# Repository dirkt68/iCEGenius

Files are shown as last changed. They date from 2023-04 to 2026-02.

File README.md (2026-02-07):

# iCEGenius (WIP)

**STILL A WORK IN PROGRESS, DONT USE UNTIL THIS MESSAGE IS GONE**

A low cost, low power, minimally sized FPGA development board based on the iCE40LP384 FPGA.

## Table of Contents
- [iCEGenius (WIP)](#icegenius-wip-1)
  - [Table of Contents](#table-of-contents-1)
  - [Project Goal](#project-goal-1)
  - [Setup](#setup-1)
  - [Directory Structure](#directory-structure-1)
  - [Support](#support-1)
  - [Wishlist](#wishlist-1)
  - [Author Information](#author-information-1)

## Project Goal

Hobbyist grade FPGAs are in relatively short supply and are typically complicated for new users to dive into. Even the cheapest ones still range in the 30-40 dollar territory, which can be prohibitively expensive for institutions or groups without a large budget. To fill this void, the iCEGenius has been developed as an educational tool for use in learning introductory to intermediate Verilog on a real hardware target.

{INSERT 3D RENDER PIC}

The iCEGenius has been designed with cost and ease of use in mind. The total bill of materials is only $13.00 USD, which is cheaper than any of the common development FPGAs on the market. The board is designed to fit comfortably into a standard breadboard with space for multiple connections on either pin. With 16 accessible GPIOs, the board is very expandable for anything from simple blinky LEDs to more complex designs.

{INSERT PIC OF BOARD ON BREADBOARD}

The toolchain is a Visual Studio Code extension which supports one click simulations using iverilog and gtkwave and full synthesis using yosys and nextpnr. The [oss-cad-suite](https://github.com/YosysHQ/oss-cad-suite-build) was used as the main backend as all the necessary programs were included by default. A custom program designed to flash the bitstream using the MCP2210 USB-SPI interface is used as the uploader. All of the complicated command line work is handled by the extension, allowing for a low barrier to entry to those who want to learn.

The PCB was developed in Kicad 7.0 and the extension supports Visual Studio Code 1.77.0 and greater.

**IMPORTANT: ONLY WINDOWS IS SUPPORTED AT THIS TIME**

## Setup

1. Grab the latest binary of oss-cad-suite from https://github.com/YosysHQ/oss-cad-suite-build and extract to `C:/oss-cad-suite`.
2. Install the latest binary of the iCEGenius Programmer from the [`Releases`](https://github.com/dirkt68/iCEGenius/releases/) Tab.
3. Install [Visual Studio Code](https://code.visualstudio.com) and install the iCEGenius (ADD HYPERLINK TO EXTENSION) extension.
4. Write some Verilog and upload to your board!

## Directory Structure

- board (where anything related to PCB lives)
  - bom (bill of materials for v2 and v1)
  - iCEGenius-backups (kicad automatic backups)
  - information (datasheets and a pinout guide for the FPGA)
  - jlcpcb (where the production files are autogenerated (gerbers, cpl, etc.))
  - pdf (easy reference to schematic and layout)
  - sims (electronic simulations)
  - kicad board files (open in kicad)
- extension (where the vscode extension lives)
  - standard Visual Studio Code layout for an extension
- programmer (where the program to program the board lives)
  - etc (user guides, etc.)
  - includes (*.h files)
  - libs (*.lib files)
  - src (main code)

## Support
- Any suggestions are welcome! I will not be super active all the time, but I'd like to maintain the project as much as I can.

## Wishlist
- add linux and mac support
- host a prebuilt board somewhere where people can buy (where?)

## Author Information
- Made by Dirk Thieme for use in ECE 2372 for the Capstone Project Lab at Texas Tech University. Advised by Derek A. Johnston.

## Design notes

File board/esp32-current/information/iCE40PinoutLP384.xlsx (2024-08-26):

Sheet: Pinout
iCE40 Pinout LP384
Ball Function | Pin Type | Bank | (SG32) 32-Pin QFN Ball Number
IOL_1A | DPIO | 3 | -
IOL_1B | DPIO | 3 | -
IOL_2A | DPIO | 3 | 2 |  |  | 1 | 2 | 3 | 4 | 5 | 6 | 7 | 8
IOL_2B | DPIO | 3 | 1 |  |  | IO_2A | IO_2B | GND | VCCIO_3 | IOL_4A | IOL_4B_GBIN7 | IOL_5B | IOL_5A_GBIN6
IOL_3A | DPIO | 3 | - | 32 | IOT_52 |  |  |  |  |  |  |  |  | VCCIO_2 | 9
IOL_3B | DPIO | 3 | - | 31 | IOT_53 |  |  |  |  |  |  |  |  | CRESET_B | 10
IOL_4A | DPIO | 3 | 5 | 30 | IOT_50_GBIN1 |  |  |  |  |  |  |  |  | CDONE | 11
IOL_4B_GBIN7 | GBIN | 3 | 6 | 29/CLK_IN | IOT_49_GBIN0 |  |  |  | FPGA Pin Numbering |  |  |  |  | IOB_24_SDO | 12
IOL_5A_GBIN6 | GBIN | 3 | 8 | 28 | VCCIO_0 |  |  |  |  |  |  |  |  | IOB_25_SDI | 13
IOL_5B | DPIO | 3 | 7 | 27 | IOT_47 |  |  |  |  | I/O Pins (use) |  |  |  | IOB_26_SCK | 14
IOL_6A | DPIO | 3 | - | 26 | IOT_45 |  |  |  |  | Reserved (no use) |  |  |  | IOB_27_SS | 15
IOL_6B | DPIO | 3 | - | 25 | VCC |  |  |  |  |  |  |  |  | VCC_SPI | 16
IOL_7A | DPIO | 3 | - |  |  | VPP_2V5 | IOR_39 | IOR_38 | GND | IOR_36_GBIN2 | IOR_35_GBIN3 | IOR_34 | VCCIO_1
IOL_7B | DPIO | 3 | - |  |  | 24 | 23 | 22 | 21 | 20 | 19 | 18 | 17
IOL_8A | DPIO | 3 | -
IOL_8B | DPIO | 3 | -
IOB_16 | PIO | 2 | -
IOB_17 | PIO | 2 | -
IOB_18 | PIO | 2 | -
IOB_19 | PIO | 2 | -
IOB_20 | PIO | 2 | -
IOB_21_GBIN5 | GBIN | 2 | -
IOB_22_GBIN4_CBSEL0 | GBIN | 2 | -
IOB_23_CBSEL1 | PIO | 2 | -
CDONE | CONFIG | 2 | 11
CRESET_B | CONFIG | 2 | 10
IOB_24_SDO | SPI | SPI | 12
IOB_25_SDI | SPI | SPI | 13
IOB_26_SCK | SPI | SPI | 15
IOB_27_SS | SPI | SPI | 14
VCC_SPI | SPI | SPI | 16
IOR_28 | PIO | 1 | -
IOR_29 | PIO | 1 | -
IOR_30 | PIO | 1 | -
IOR_31 | PIO | 1 | -
IOR_33 | PIO | 1 | -
IOR_34 | PIO | 1 | 18
IOR_35_GBIN3 | GBIN | 1 | 19
IOR_36_GBIN2 | GBIN | 1 | 20
IOR_37 | PIO | 1 | -
IOR_38 | PIO | 1 | 22
IOR_39 | PIO | 1 | 23
IOR_40 | PIO | 1 | -
IOR_41 | PIO | 1 | -
IOR_42 | PIO | 1 | -
IOR_43 | PIO | 1 | -
VPP_2V5 | VPP | VPP | 24
VPP_FAST | VPP | VPP | -
IOT_44 | PIO | 0 | -
IOT_45 | PIO | 0 | 26
IOT_46 | PIO | 0 | -
IOT_47 | PIO | 0 | 27
IOT_48 | PIO | 0 | -
IOT_49_GBIN0 | GBIN | 0 | 29
IOT_50_GBIN1 | GBIN | 0 | 30
IOT_51 | PIO | 0 | -
IOT_52 | PIO | 0 | 32
IOT_53 | PIO | 0 | 31
IOT_54 | PIO | 0 | -
IOT_55 | PIO | 0 | -
GND | GND | GND | 3
GND | GND | GND | 21
GND | GND | GND | -
GND | GND | GND | -
VCC | VCC | VCC | 25
VCC | VCC | VCC | -
VCC | VCC | VCC | -
VCCIO_0 | VCCIO | VCCIO | 28
VCCIO_1 | VCCIO | VCCIO | 17
VCCIO_2 | VCCIO | VCCIO | 9
VCCIO_3 | VCCIO | VCCIO | 4
VCCIO_2_3 | VCCIO | VCCIO | -

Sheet: Revision History
Version | Date | Description
1.1 | 2013-06-27 | Removal of CM81 package. Included package ordering code.
1.0 | 2013-03-13 | Initial Release

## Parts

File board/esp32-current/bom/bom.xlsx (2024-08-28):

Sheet: v2
Mouser Part Number | Part Name | Price | Amount/Unit | Sub-Total | Notes | Total/Amt | Desired Amt
842-ICE40LP384SG32 | ICE40LP384-SG32 | $2.28 | 1 | $2.28 | FPGA | $13.44 | 1
454-W25Q80DVSNIG | W25Q80DVSNIG | $0.49 | 1 | $0.49 | SPI Flash - 8Mb
579-MCP1727-3302E/MF | MCP1727-3302E/MF | $1.11 | 1 | $1.11 | 3V3 Regulator | Total/Unit
998-MIC5365-1.2YC5TR | MIC5365-1.2YC5-TR | $0.19 | 1 | $0.19 | 1V2 Regulator | $13.44
833-1N4148W-TP | 1N4148W-TP | $0.11 | 1 | $0.11 | Diode to Drop 3V3 to ~2.5V
520-TXO32CSMV400BNTR | ECS-TXO-32CSMV-400-BN-TR | $1.93 | 1 | $1.93 | 40MHz TCXO | Savings from v1
998-PL133-27GC-R | PL133-27GC-R | $0.97 | 1 | $0.97 | Clock 1:2 Buffer | 5.485232068%
356-ESP32-C6FH4 | ESP32-C6FH4 | $2.06 | 1 | $2.06 | USB-SPI Bridge
187-CL05A105KO5NNND | CL05A105KO5NNND | $0.04 | 13 | $0.52 | 1u X5R 0402 10% Cap
81-GRM155R61A106ME1J | GRM155R61A106ME11J | $0.11 | 2 | $0.22 | 10u X5R 0402 20% Cap
581-0201ZD104KAT4A | 0201ZD104KAT4A | $0.02 | 14 | $0.28 | 100n X5R 0201 10% Cap
791-RGC1/16SC5101DTH | RGC1/16SC5101DTH | $0.10 | 2 | $0.20 | 5.1k 0402 0.5% Res
756-ASC0402-10KFT10 | ASC0402-10KFT10 | $0.08 | 6 | $0.48 | 10k 0402 1% Res
81-LQG15HZ2N0B02D | LQG15HZ2N0B02D | $0.17 | 1 | $0.17 | 2n 0.9A Inductor
640-USB4105-GF-A-060 | USB4105-GF-A-060 | $0.81 | 1 | $0.81 | USB C Connector
710-150060RS75000 | 150060RS75000 | $0.15 | 1 | $0.15 | Red LED 0603
963-MAASL063SB7103KF | MAASL063SB7103KFCA01 | $0.12 | 1 | $0.12 | 0.01n X7R 10% 0201 10% Cap
595-ESD321DYAR | ESD321DYAR | $0.45 | 3 | $1.35 | ESD Diodes

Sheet: v1
Mouser Part Number | Part Name | Price | Amount/Unit | Sub-Total | Notes | Total/Unit
842-ICE40LP384SG32 | ICE40LP384-SG32 | $2.17 | 1 | $2.17 | FPGA | $14.22
454-W25Q80DVSNIG | W25Q80DVSNIG | $0.52 | 1 | $0.52 | SPI Flash - 8Mb
621-PI5C3257ZHDEX | PI5C3257ZHDEX | $0.60 | 1 | $0.60 | SPI MUX
595-TLV74033PDBVR | TLV74033PDBVR | $0.25 | 1 | $0.25 | 3V3 Regulator
998-MIC5365-1.2YC5TR | MIC5365-1.2YC5-TR | $0.19 | 1 | $0.19 | 1V2 Regulator
833-1N4148W-TP | 1N4148W-TP | $0.10 | 1 | $0.10 | Diode to Drop 3V3 to ~2.5V
815-ABM8AIG-12MHZ1ZT | ABM8AIG-12.000MHZ-1Z-T | $0.72 | 1 | $0.72 | 12MHz Clock
895-FT4222HQ-D-T | FT4222HQ-D-T | $3.62 | 1 | $3.62 | USB-SPI IC
187-CL05A105KO5NNND | CL05A105KO5NNND | $0.04 | 14 | $0.56 | 1u X5R 0402 10% Cap
81-GRM0335C1E240GA1D | GRM0335C1E240GA01D | $0.10 | 2 | $0.20 | 24p C0G 0201 2% Cap
603-CC402KRX5R6BB474 | CC0402KRX5R6BB474 | $0.10 | 1 | $0.10 | 470n X7R 0402 10% Cap
581-0201ZD104KAT4A | 0201ZD104KAT4A | $0.02 | 12 | $0.24 | 0.1u X5R 0201 10% Cap
791-RGC1/16SC5101DTH | RGC1/16SC5101DTH | $0.10 | 2 | $0.20 | 5.1k 0402 0.5% Res
603-RC0402FR-1312KL | RC0402FR-1312KL | $0.01 | 7 | $0.07 | 12k 0402 1% Res
756-ASC0402-10KFT10 | ASC0402-10KFT10 | $0.08 | 5 | $0.40 | 10k 0402 1% Res
71-CRCW04021M00FKEE | CRCW04021M00FKEE | $0.10 | 1 | $0.10 | 1M 0402 1% Res
640-USB4105-GF-A-060 | USB4105-GF-A-060 | $0.81 | 1 | $0.81 | USB C Connector
710-150060RS75000 | 150060RS75000 | $0.15 | 1 | $0.15 | Red LED 0603
576-SC1006-01LTG | SC1006-01LTG | $0.45 | 3 | $1.35 | ESD Diodes
Slide Switch |  | $1.87 | 1 | $1.87 | Don’t remember exact

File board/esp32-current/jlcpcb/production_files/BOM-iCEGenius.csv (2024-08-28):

Comment | Designator | Footprint | LCSC
1u | C1 | C_0402_1005Metric
100n | C10 | C_0201_0603Metric
100n | C11 | C_0201_0603Metric
100n | C12 | C_0201_0603Metric
1u | C13 | C_0402_1005Metric
100n | C14 | C_0201_0603Metric
100n | C15 | C_0201_0603Metric
100n | C16 | C_0201_0603Metric
1u | C17 | C_0402_1005Metric
100n | C18 | C_0201_0603Metric
1u | C19 | C_0402_1005Metric
10u | C2 | C_0402_1005Metric
100n | C20 | C_0201_0603Metric
1u | C21 | C_0402_1005Metric
100n | C22 | C_0201_0603Metric
1u | C23 | C_0402_1005Metric
100n | C24 | C_0201_0603Metric
1u | C25 | C_0402_1005Metric
100n | C26 | C_0201_0603Metric
1u | C27 | C_0402_1005Metric
100n | C28 | C_0201_0603Metric
1u | C29 | C_0402_1005Metric
1u | C3 | C_0402_1005Metric
100n | C30 | C_0201_0603Metric
1u | C4 | C_0402_1005Metric
1u | C5 | C_0402_1005Metric
10n | C6 | C_0201_0603Metric
10u | C7 | C_0402_1005Metric
1u | C8 | C_0402_1005Metric
100n | C9 | C_0201_0603Metric
1N4148W-TP | D1 | D_SOD-123
ESD321 | D2 | D_0402_1005Metric_TVS
ESD321 | D3 | D_0402_1005Metric_TVS
ESD321 | D4 | D_0402_1005Metric_TVS
FPGA_DONE_G | D5 | LED_0603_1608Metric
USB4105-GF-A-060 | J1 | USB_C_Receptacle_GCT_USB4105-xx-A_16P_TopMnt_Horizontal
LEFT | J2 | PinSocket_1x10_P2.54mm_Vertical
RIGHT | J3 | PinSocket_1x10_P2.54mm_Vertical
LQG15HZ2N0B02D | L1 | L_0402_1005Metric
5k1 | R1 | R_0402_1005Metric
5k1 | R2 | R_0402_1005Metric
10k | R3 | R_0402_1005Metric
10k | R4 | R_0402_1005Metric
10k | R5 | R_0402_1005Metric
10k | R6 | R_0402_1005Metric
10k | R7 | R_0402_1005Metric
10k | R8 | R_0402_1005Metric
MCP1727-3302xMF | U1 | DFN-8-1EP_3x3mm_P0.65mm_EP1.55x2.4mm
MIC5365-1.2YC5 | U2 | SOT-353_SC-70-5
ESP32-C6FH4 | U3 | QFN50P500X500X90-33N
W25Q80DVSNIG | U4 | SOIC127P600X175-8N
ICE40LP384-SG32 | U5 | HVQFN-32-1EP_5x5mm_P0.5mm_EP3.1x3.1mm
PL133-27GC-R | U6 | SON40P200X130X60-7N-D
ECS-TXO-32CSMV-400-BN-TR | Y1 | ECSTXO32CSMV400BNTR

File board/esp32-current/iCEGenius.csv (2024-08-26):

Source: | D:\Documents\School\TTU\summer23\project-lab-4\iCEGenius\board\iCEGenius.kicad_sch
Date: | Tue Jun 27 13:58:00 2023
Tool: | Eeschema 7.0.2
Generator: | C:\Program Files\KiCad\7.0\bin\scripting\plugins/bom_csv_grouped_by_value.py
Component Count: | 52
Collated Components:
Item | Qty | Reference(s) | Value | LibPart | Footprint | Datasheet | DNP | Height | MANUFACTURER | Manufacturer_Name | Manufacturer_Part_Number | Mouser Part Number | Mouser Price/Stock | Sim.Device | Sim.Pins
1 | 12 | C1, C2, C3, C4, C5, C12, C14, C16, C18, C20, C22, C24 | 1u | Device:C_Small | Capacitor_SMD:C_0402_1005Metric | ~
2 | 10 | C6, C9, C10, C13, C15, C17, C19, C21, C23, C25 | 100n | Device:C_Small | Capacitor_SMD:C_0201_0603Metric | ~
3 | 2 | C7, C8 | 24p | Device:C_Small | Capacitor_SMD:C_0201_0603Metric | ~
4 | 1 | C11 | 10n | Device:C_Small | Capacitor_SMD:C_0201_0603Metric | ~
5 | 1 | D1 | 1N4148W-TP | Device:D_Small_Filled | Diode_SMD:D_SOD-123 | ~ |  |  |  |  |  |  |  | D | 1=K 2=A
6 | 3 | D2, D3, D4 | SC1006-01LTG | Device:D_TVS_Filled | PCM_Diode_SMD_AKL:D_SOD-523_TVS | ~
7 | 1 | D5 | CDONE | Device:LED_Small | PCM_Diode_SMD_AKL:D_0603_1608Metric | ~
8 | 1 | IC1 | MCP2210-I_MQ | SamacSys_Parts:MCP2210-I_MQ | SamacSys_Parts:QFN65P500X500X100-21N-D |  |  | 1 |  | Microchip | MCP2210-I/MQ | 579-MCP2210IMQ | https://www.mouser.co.uk/ProductDetail/Microchip-Technology/MCP2210-I-MQ?qs=hort8UWU32pLWgskQOyvyg%3D%3D
9 | 1 | J1 | USB4105-GF-A-060 | Connector:USB_C_Receptacle_USB2.0 | Connector_USB:USB_C_Receptacle_GCT_USB4105-xx-A_16P_TopMnt_Horizontal | https://www.usb.org/sites/default/files/documents/usb_type-c.zip
10 | 1 | J2 | LEFT | Connector:Conn_01x10_Pin | Connector_PinSocket_2.54mm:PinSocket_1x10_P2.54mm_Vertical | ~
11 | 1 | J3 | RIGHT | Connector:Conn_01x10_Pin | Connector_PinSocket_2.54mm:PinSocket_1x10_P2.54mm_Vertical | ~
12 | 1 | Q1 | MMBT3904-TP | PCM_Transistor_BJT_AKL:MMBT3904 | PCM_Package_TO_SOT_SMD_AKL:SOT-23 | https://www.tme.eu/Document/12bff749841e3a356e683e9a8e7e4119/2N3904BU-DTE.pdf
13 | 2 | R1, R2 | 5k1 | Device:R_Small | Resistor_SMD:R_0402_1005Metric | ~
14 | 1 | R3 | 1M | Device:R_Small | Resistor_SMD:R_0402_1005Metric | ~
15 | 8 | R4, R5, R6, R7, R8, R9, R10, R11 | 10k | Device:R_Small | Resistor_SMD:R_0402_1005Metric | ~
16 | 1 | U1 | BU33SD5WG-TR | SamacSys_Parts:BU33SD5WG-TR | SOT95P280X125-5N | https://componentsearchengine.com/Datasheets/1/BU33SD5WG-TR.pdf |  | 1.25 |  | ROHM Semiconductor | BU33SD5WG-TR | 755-BU33SD5WG-TR | https://www.mouser.co.uk/ProductDetail/ROHM-Semiconductor/BU33SD5WG-TR?qs=%2FKR40Cd6GUrQDzRkUEt69Q%3D%3D
17 | 1 | U2 | MIC5365-1.2YC5 | Regulator_Linear:MIC5365-3.3YC5 | Package_TO_SOT_SMD:SOT-353_SC-70-5 | http://ww1.microchip.com/downloads/en/DeviceDoc/mic5365.pdf
18 | 1 | U3 | W25Q80DVSNIG | SamacSys_Parts:W25Q80DVSNIG | SamacSys_Parts:SOIC127P600X175-8N | https://www.winbond.com/hq/search-resource-file.jsp?partNo=W25Q80DVSNIG&type=datasheet |  | 1.75 |  | Winbond | W25Q80DVSNIG | 454-W25Q80DVSNIG | https://www.mouser.co.uk/ProductDetail/Winbond/W25Q80DVSNIG?qs=qSfuJ%252Bfl%2Fd4U6qBd6DZUig%3D%3D
19 | 1 | U4 | ICE40LP384-SG32 | ICE40LP384-SG32:ICE40LP384-SG32 | Package_DFN_QFN:HVQFN-32-1EP_5x5mm_P0.5mm_EP3.1x3.1mm |  |  |  | Lattice Semiconductor
20 | 1 | Y1 | 815-ABM8AIG-12MHZ1ZT | Device:Crystal_GND24 | SamacSys_Parts:ABM8AIG25000MHZ122ZT3 | ~
21 | 1 | Y2 | ASFL1-100.000MHZ-L-T | SamacSys_Parts:ASFL1-100.000MHZ-L-T | SamacSys_Parts:ASFL1 | https://abracon.com/Oscillators/ASFL1.pdf |  | 1.3 |  | ABRACON | ASFL1-100.000MHZ-L-T

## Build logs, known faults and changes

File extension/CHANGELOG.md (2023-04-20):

# Change Log

All notable changes to the "iCEGenius-extension" extension will be documented in this file.

Check [Keep a Changelog](http://keepachangelog.com/) for recommendations on how to structure this file.

## [Unreleased]

- Initial release

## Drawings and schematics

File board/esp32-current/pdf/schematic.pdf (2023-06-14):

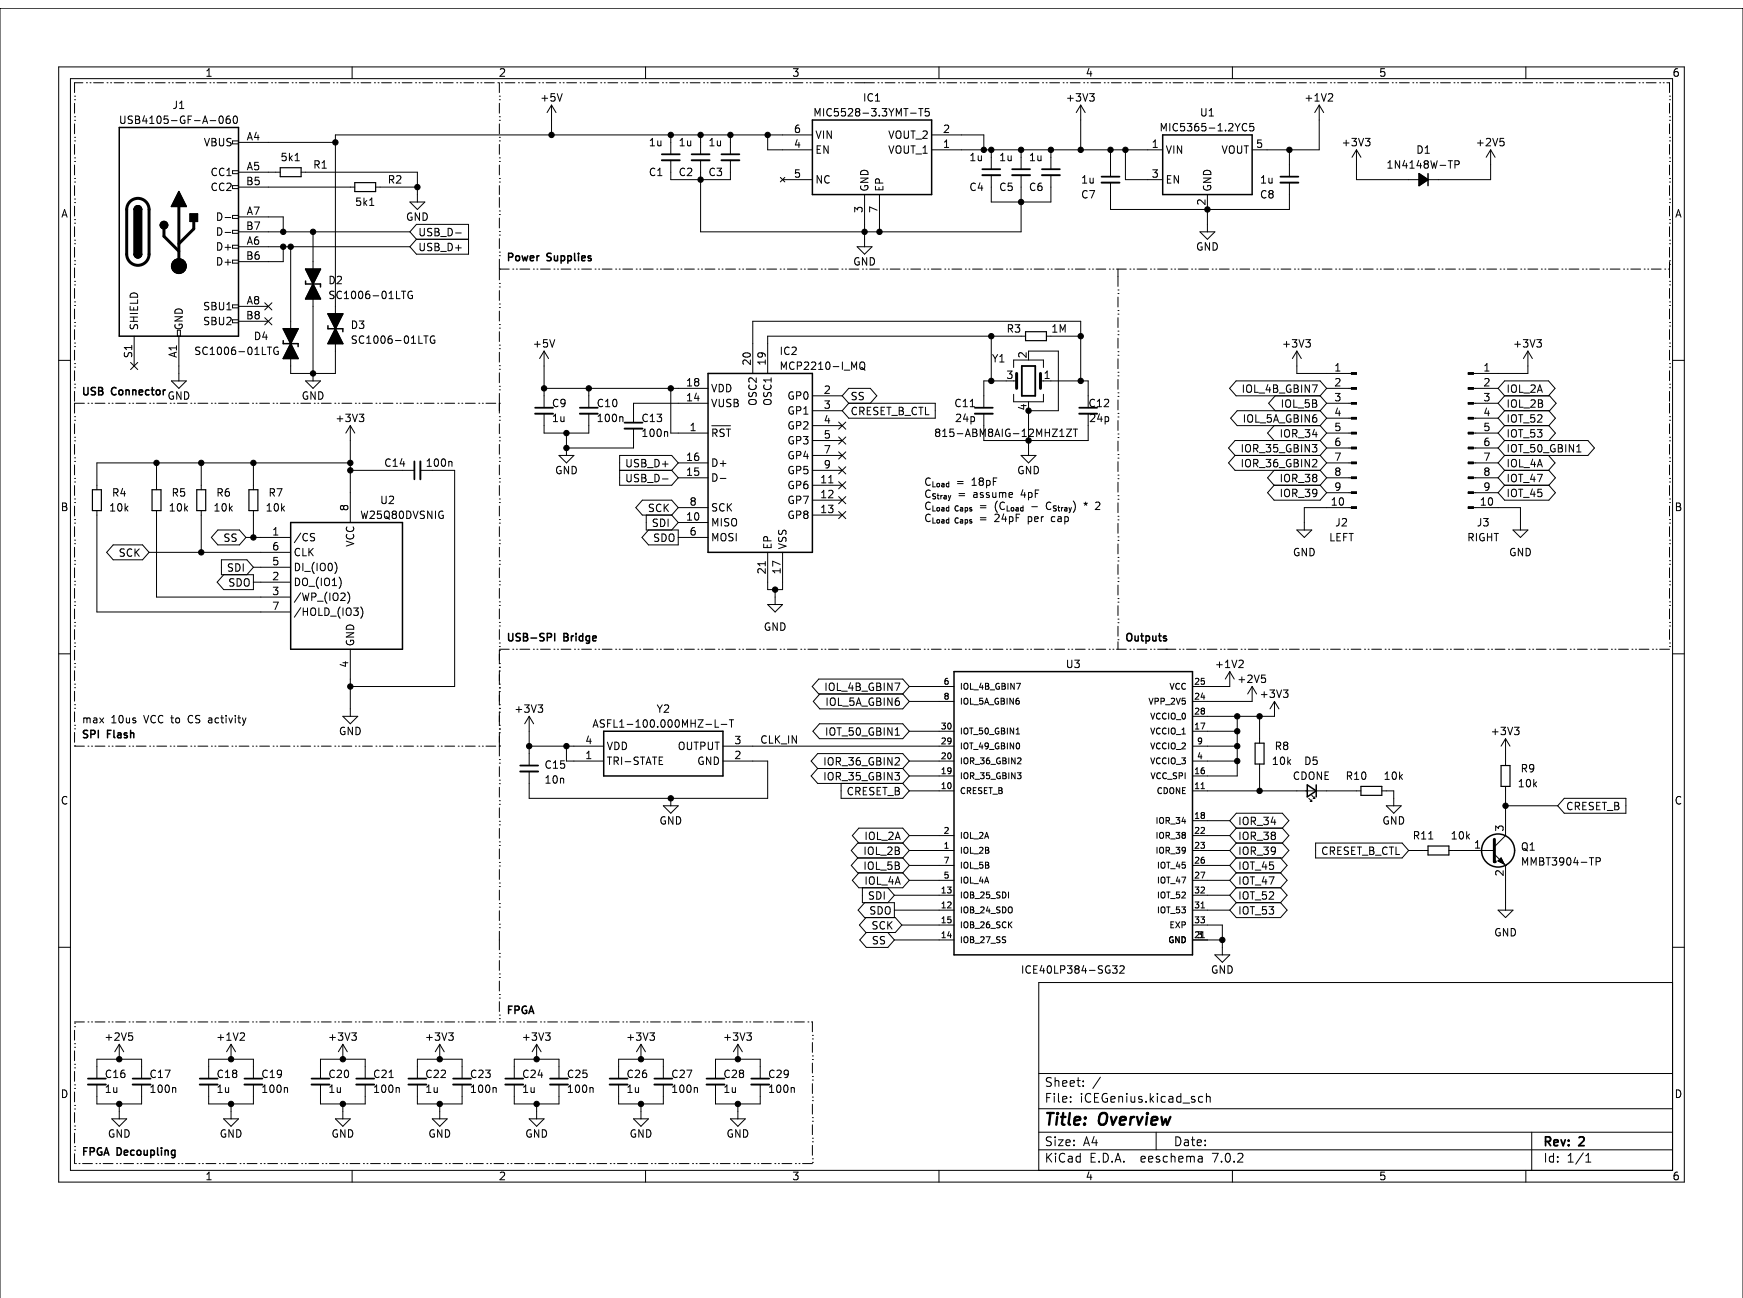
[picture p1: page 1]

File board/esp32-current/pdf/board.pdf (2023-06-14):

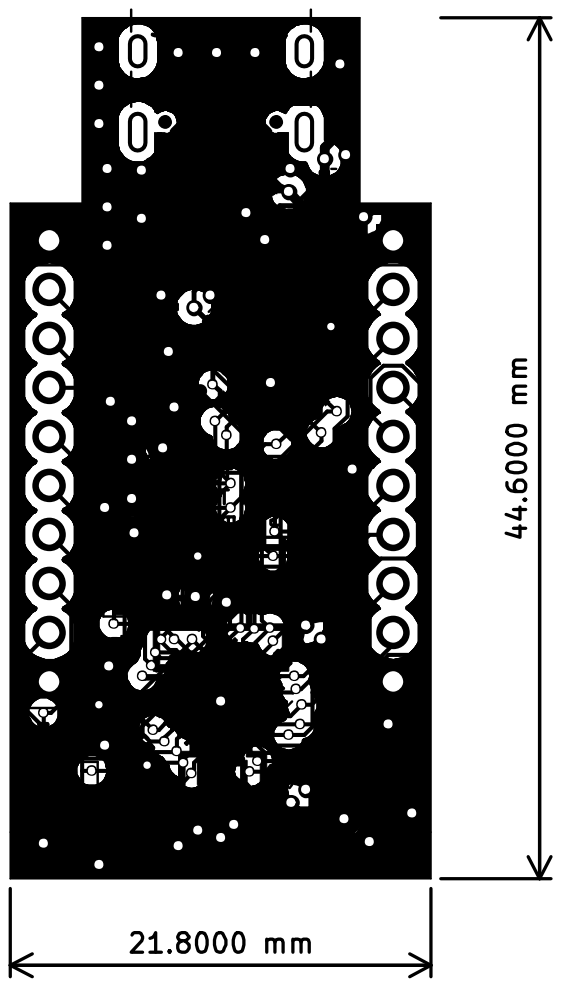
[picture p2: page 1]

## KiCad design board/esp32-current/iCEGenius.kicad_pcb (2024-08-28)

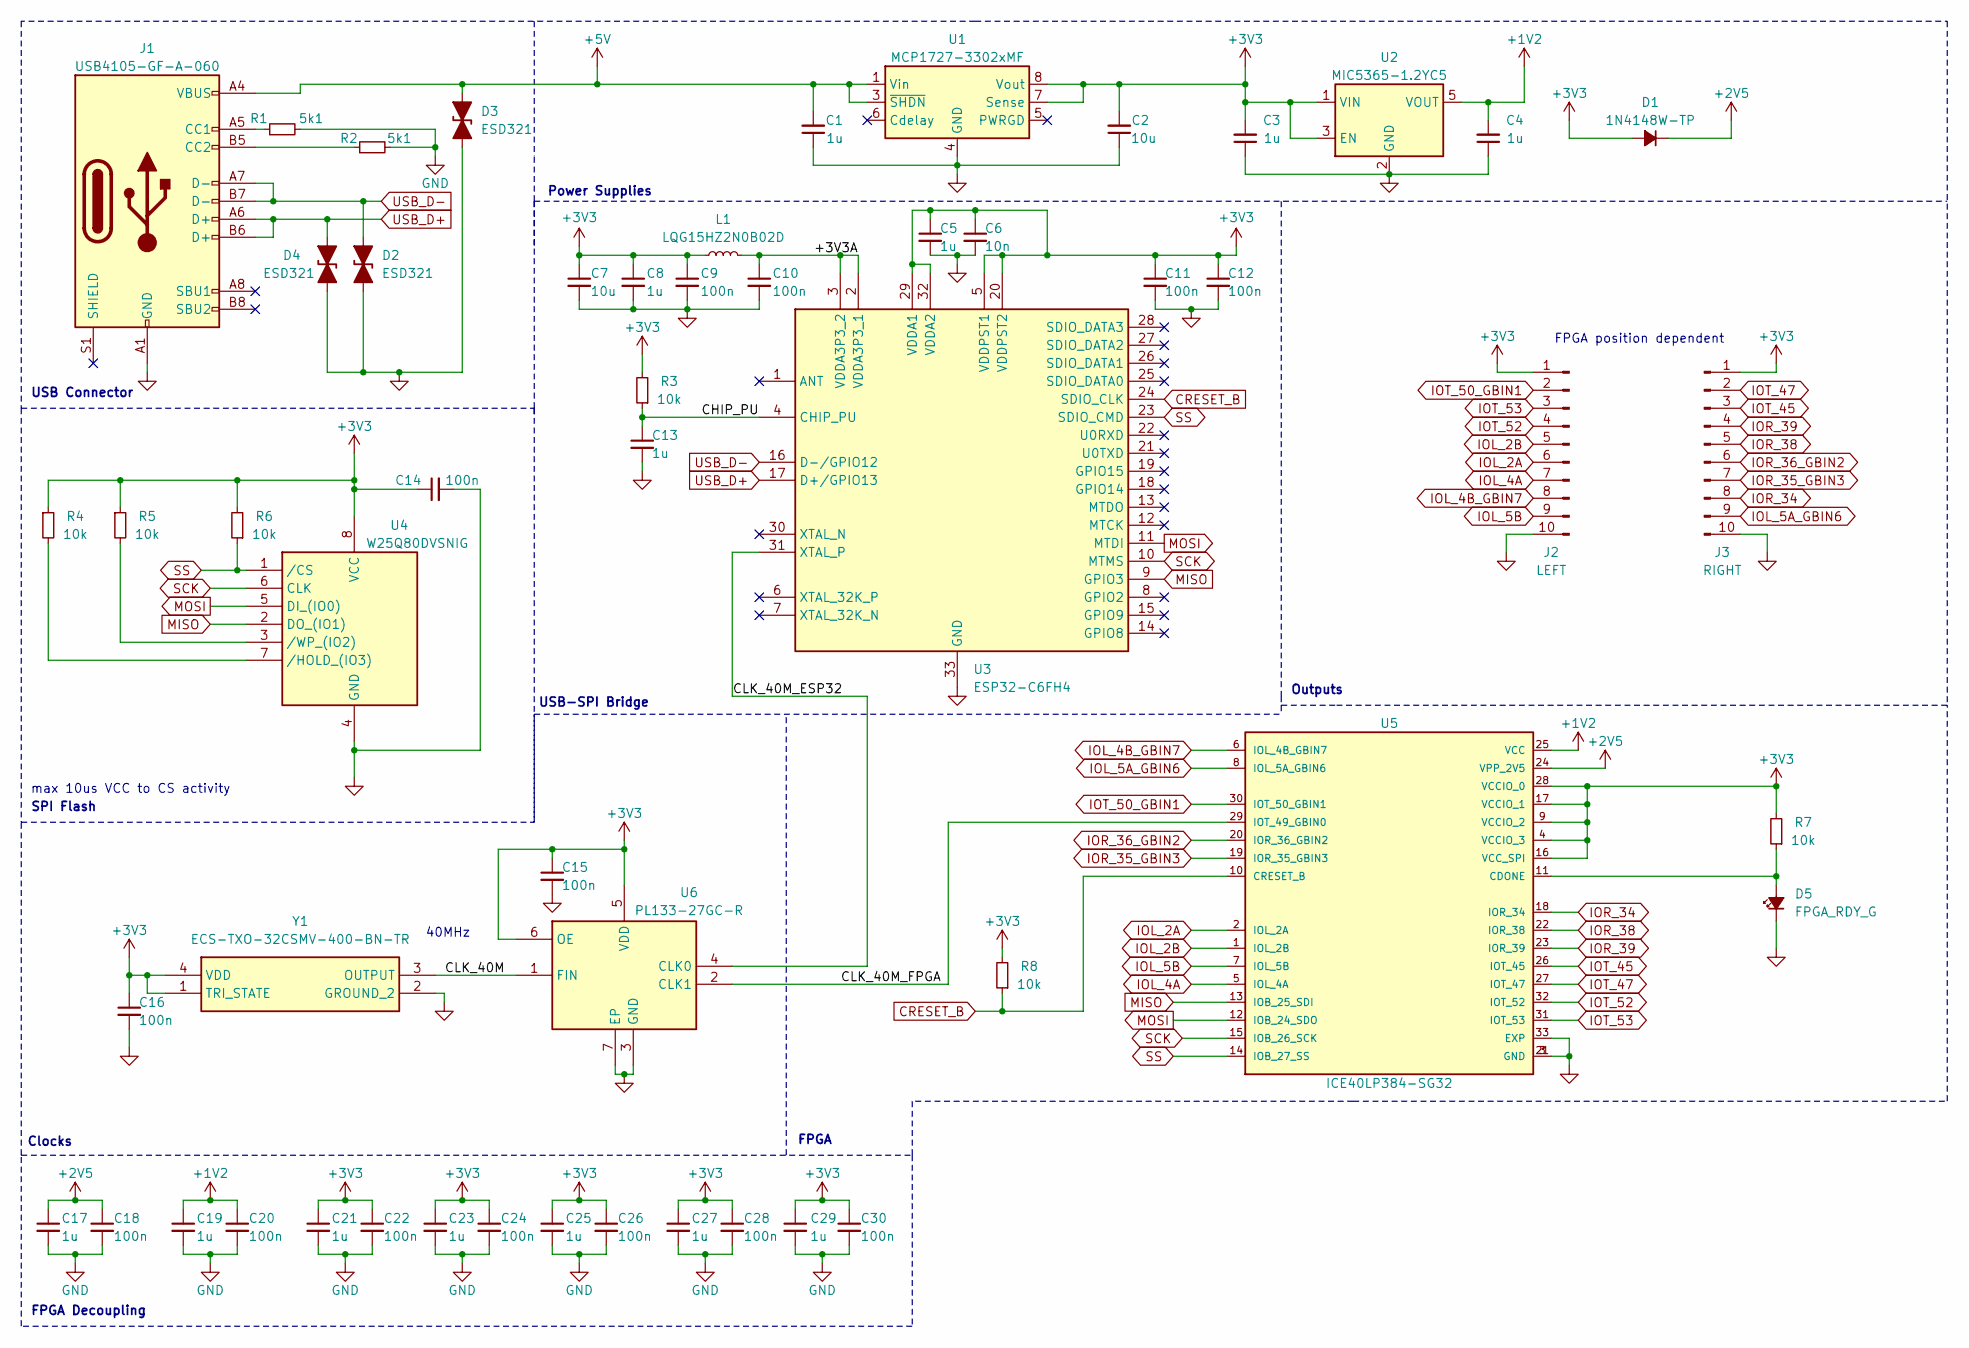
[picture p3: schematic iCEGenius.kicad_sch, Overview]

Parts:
C1, C3, C4, C5, C8, C13, C17, C19, C21, C23, C25, C27, C29: 1u; C_0402_1005Metric
C2, C7: 10u; C_0402_1005Metric
C6: 10n; C_0201_0603Metric
C9, C10, C11, C12, C14, C15, C16, C18, C20, C22, C24, C26, C28, C30: 100n; C_0201_0603Metric
D1: 1N4148W-TP; D_SOD-123
D2, D3, D4: ESD321; D_0402_1005Metric_TVS
D5: FPGA_RDY_G; LED_0603_1608Metric
J1: USB4105-GF-A-060; USB_C_Receptacle_GCT_USB4105-xx-A_16P_TopMnt_Horizontal
J2: LEFT; PinSocket_1x10_P2.54mm_Vertical
J3: RIGHT; PinSocket_1x10_P2.54mm_Vertical
L1: LQG15HZ2N0B02D; L_0402_1005Metric
R1, R2: 5k1; R_0402_1005Metric
R3, R4, R5, R6, R7, R8: 10k; R_0402_1005Metric
U1: MCP1727-3302xMF; DFN-8-1EP_3x3mm_P0.65mm_EP1.55x2.4mm
U2: MIC5365-1.2YC5; SOT-353_SC-70-5
U3: ESP32-C6FH4; QFN50P500X500X90-33N; Mouser Part Number 356-ESP32-C6FH4
U4: W25Q80DVSNIG; SOIC127P600X175-8N; Mouser Part Number 454-W25Q80DVSNIG
U5: ICE40LP384-SG32; HVQFN-32-1EP_5x5mm_P0.5mm_EP3.1x3.1mm
U6: PL133-27GC-R; SON40P200X130X60-7N-D; Mouser Part Number 998-PL133-27GC-R
Y1: ECS-TXO-32CSMV-400-BN-TR; ECSTXO32CSMV400BNTR; Mouser Part Number 520-TXO32CSMV400BNTR

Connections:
+1V2: C4.2, C19.1, C20.1, U2.5 (VOUT), U5.25 (VCC)
+2V5: C17.1, C18.1, D1.1 (K), U5.24 (VPP_2V5)
+3V3: C2.2, C3.2, C5.1, C6.1, C7.1, C8.1, C9.1, C11.1, C12.1, C14.1, C15.1, C16.1, C21.1, C22.1, C23.1, C24.1, C25.1, C26.1, C27.1, C28.1, C29.1, C30.1, D1.2 (A), J2.1, J3.1, L1.1, R3.2, R4.1, R5.1, R6.2, R7.2, R8.2, U1.7 (Sense), U1.8 (Vout), U2.1 (VIN), U2.3 (EN), U3.5 (VDDPST1), U3.20 (VDDPST2), U3.29 (VDDA1), U3.32 (VDDA2), U4.8 (VCC), U5.4 (VCCIO_3), U5.9 (VCCIO_2), U5.16 (VCC_SPI), U5.17 (VCCIO_1), U5.28 (VCCIO_0), U6.5 (VDD), U6.6 (OE), Y1.1 (TRI_STATE), Y1.4 (VDD)
+5V: C1.2, D3.2 (A2), J1.A4 (VBUS), J1.A9 (VBUS), J1.B4 (VBUS), J1.B9 (VBUS), U1.1 (Vin), U1.2 (Vin), U1.3 (~SHDN)
/+3V3A: C10.1, L1.2, U3.2 (VDDA3P3_1), U3.3 (VDDA3P3_2)
/CHIP_PU: C13.1, R3.1, U3.4 (CHIP_PU)
/CLK_40M: U6.1 (FIN), Y1.3 (OUTPUT)
/CLK_40M_ESP32: U3.31 (XTAL_P), U6.4 (CLK0)
/CLK_40M_FPGA: U5.29 (IOT_49_GBIN0), U6.2 (CLK1)
CRESET_B: R8.1, U3.24 (SDIO_CLK), U5.10 (CRESET_B)
GND: C1.1, C2.1, C3.1, C4.1, C5.2, C6.2, C7.2, C8.2, C9.2, C10.2, C11.2, C12.2, C13.2, C14.2, C15.2, C16.2, C17.2, C18.2, C19.2, C20.2, C21.2, C22.2, C23.2, C24.2, C25.2, C26.2, C27.2, C28.2, C29.2, C30.2, D2.1 (A1), D3.1 (A1), D4.1 (A1), D5.1 (K), J1.A1 (GND), J1.A12 (GND), J1.B1 (GND), J1.B12 (GND), J2.10, J3.10, R1.2, R2.2, U1.4 (GND), U1.9 (GND), U2.2 (GND), U3.33 (GND), U4.4 (GND), U5.3 (GND), U5.21 (GND), U5.33 (EXP), U6.3 (GND), U6.7 (EP), Y1.2 (GROUND_2)
IOL_2A: J2.6, U5.2 (IOL_2A)
IOL_2B: J2.5, U5.1 (IOL_2B)
IOL_4A: J2.7, U5.5 (IOL_4A)
IOL_4B_GBIN7: J2.8, U5.6 (IOL_4B_GBIN7)
IOL_5A_GBIN6: J3.9, U5.8 (IOL_5A_GBIN6)
IOL_5B: J2.9, U5.7 (IOL_5B)
IOR_34: J3.8, U5.18 (IOR_34)
IOR_35_GBIN3: J3.7, U5.19 (IOR_35_GBIN3)
IOR_36_GBIN2: J3.6, U5.20 (IOR_36_GBIN2)
IOR_38: J3.5, U5.22 (IOR_38)
IOR_39: J3.4, U5.23 (IOR_39)
IOT_45: J3.3, U5.26 (IOT_45)
IOT_47: J3.2, U5.27 (IOT_47)
IOT_50_GBIN1: J2.2, U5.30 (IOT_50_GBIN1)
IOT_52: J2.4, U5.32 (IOT_52)
IOT_53: J2.3, U5.31 (IOT_53)
MISO: U3.9 (GPIO3), U4.2 (DO_(IO1)), U5.13 (IOB_25_SDI)
MOSI: U3.11 (MTDI), U4.5 (DI_(IO0)), U5.12 (IOB_24_SDO)
unnamed: D5.2 (A), R7.1, U5.11 (CDONE)
unnamed: J1.A5 (CC1), R1.1
unnamed: J1.B5 (CC2), R2.1
unnamed: R4.2, U4.7 (/HOLD_(IO3))
unnamed: R5.2, U4.3 (/WP_(IO2))
SCK: U3.10 (MTMS), U4.6 (CLK), U5.15 (IOB_26_SCK)
SS: R6.1, U3.23 (SDIO_CMD), U4.1 (/CS), U5.14 (IOB_27_SS)
USB_D+: D4.2 (A2), J1.A6 (D+), J1.B6 (D+), U3.17 (D+/GPIO13)
USB_D-: D2.2 (A2), J1.A7 (D-), J1.B7 (D-), U3.16 (D-/GPIO12)

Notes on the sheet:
USB-SPI Bridge
SPI Flash
40MHz
Power Supplies
Outputs
max 10us VCC to CS activity
FPGA
Clocks
FPGA position dependent
USB Connector
FPGA Decoupling

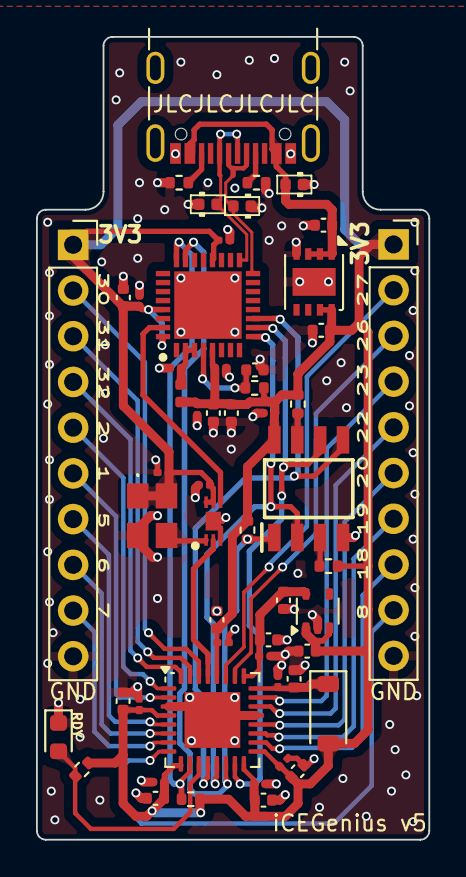
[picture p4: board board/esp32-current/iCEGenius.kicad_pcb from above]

Board: 4 copper layers, 21.8 x 44.6 mm, 54 parts (0 on the bottom side), 38 nets.

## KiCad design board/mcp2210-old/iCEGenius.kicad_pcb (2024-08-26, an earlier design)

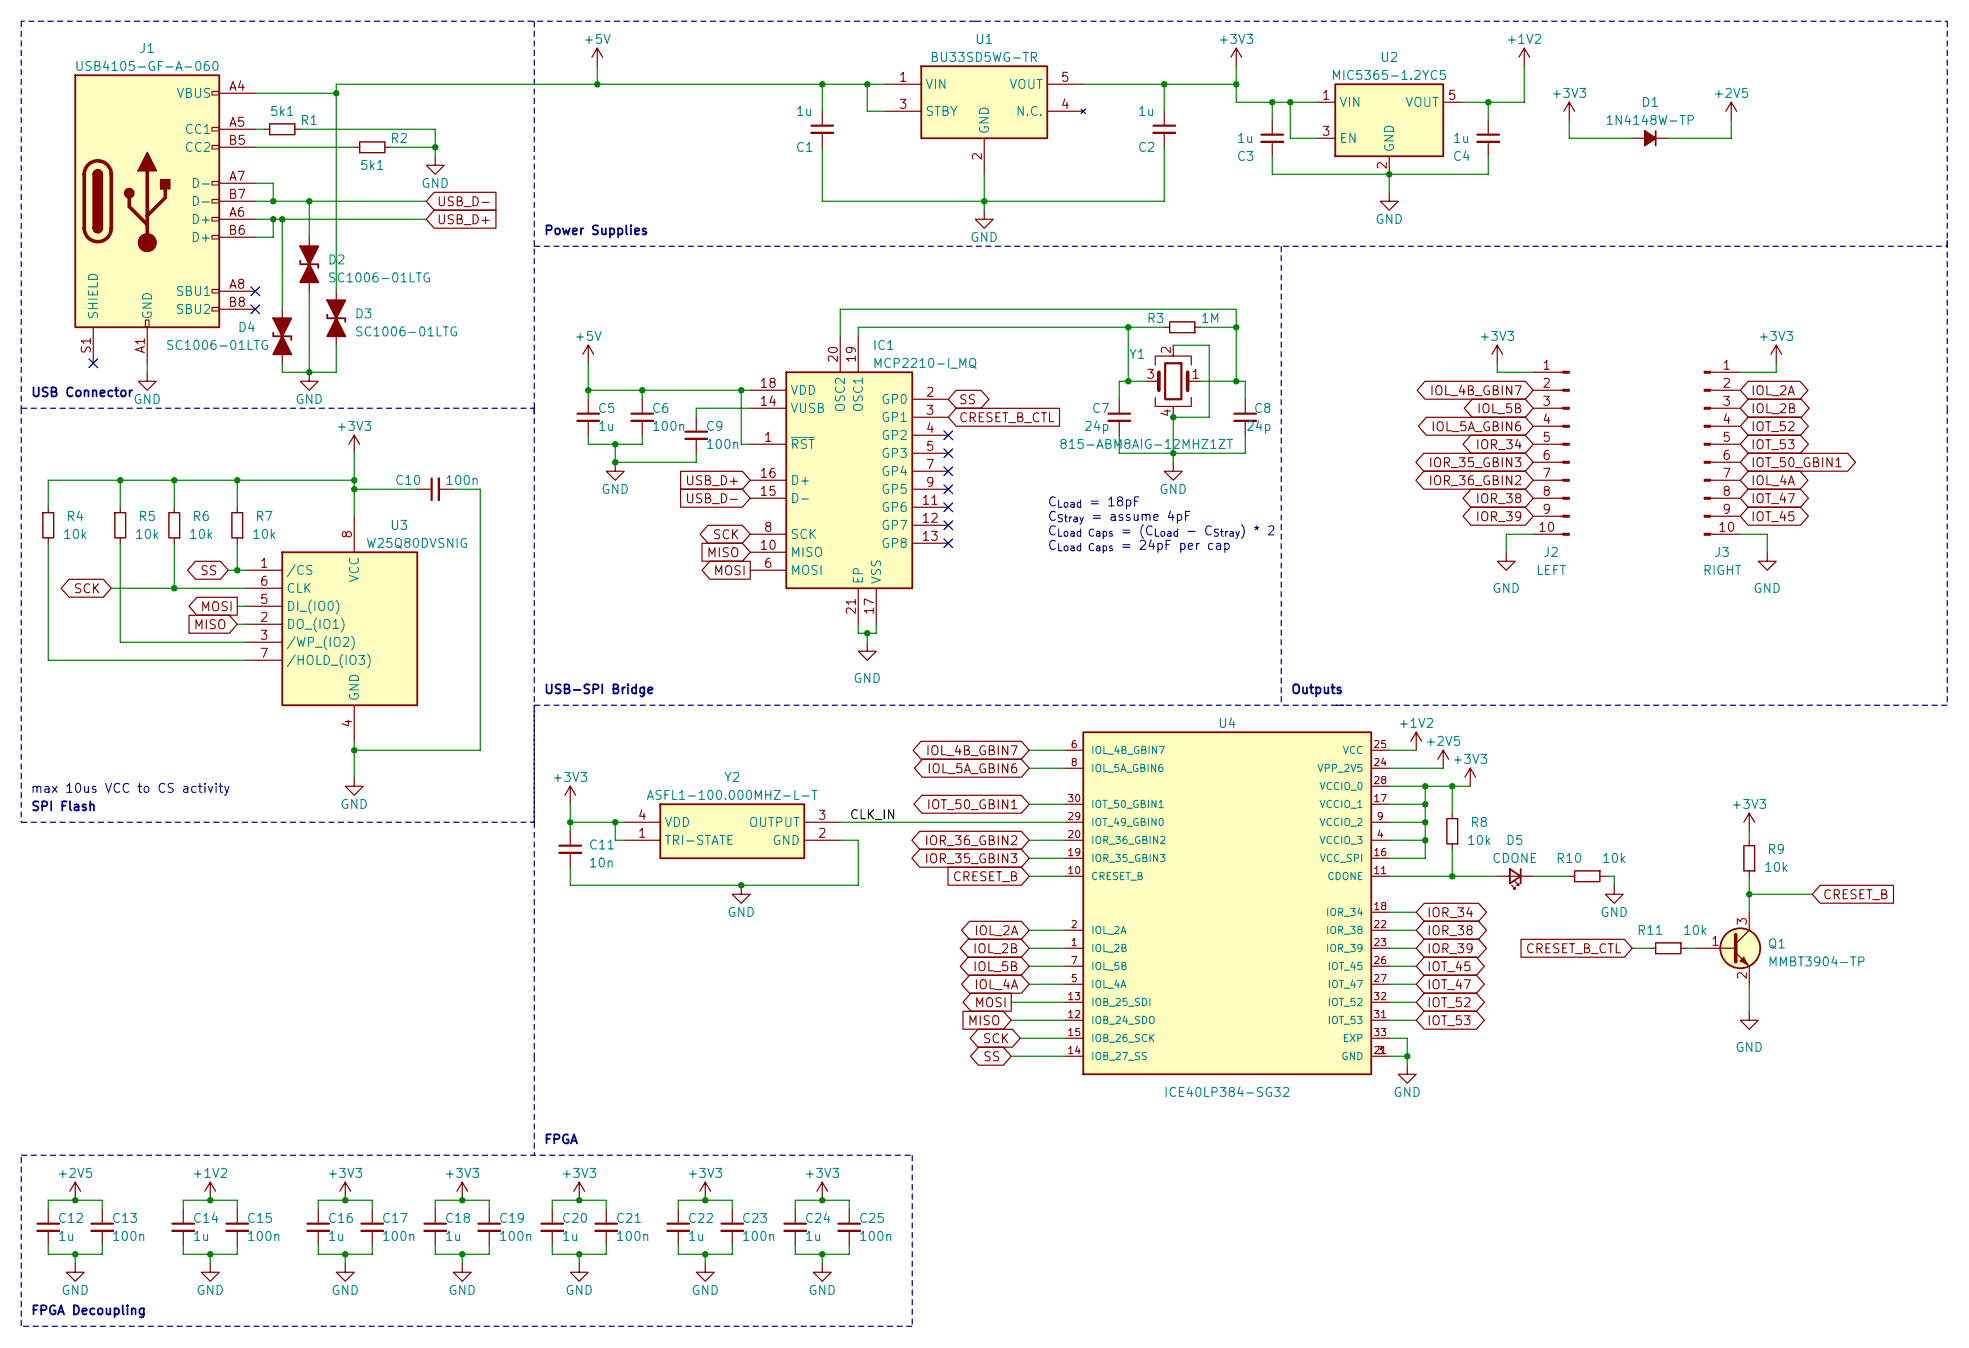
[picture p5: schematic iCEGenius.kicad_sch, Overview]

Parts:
C1, C2, C3, C4, C5, C12, C14, C16, C18, C20, C22, C24: 1u; C_0402_1005Metric
C6, C9, C10, C13, C15, C17, C19, C21, C23, C25: 100n; C_0201_0603Metric
C7, C8: 24p; C_0201_0603Metric
C11: 10n; C_0201_0603Metric
D1: 1N4148W-TP; D_SOD-123
D2, D3, D4: SC1006-01LTG; D_SOD-523_TVS
D5: CDONE; D_0603_1608Metric
IC1: MCP2210-I_MQ; QFN65P500X500X100-21N-D; Mouser Part Number 579-MCP2210IMQ
J1: USB4105-GF-A-060; USB_C_Receptacle_GCT_USB4105-xx-A_16P_TopMnt_Horizontal
J2: LEFT; PinSocket_1x10_P2.54mm_Vertical
J3: RIGHT; PinSocket_1x10_P2.54mm_Vertical
Q1: MMBT3904-TP; SOT-23
R1, R2: 5k1; R_0402_1005Metric
R3: 1M; R_0402_1005Metric
R4, R5, R6, R7, R8, R9, R10, R11: 10k; R_0402_1005Metric
U1: BU33SD5WG-TR; SOT95P280X125-5N; Mouser Part Number 755-BU33SD5WG-TR
U2: MIC5365-1.2YC5; SOT-353_SC-70-5
U3: W25Q80DVSNIG; SOIC127P600X175-8N; Mouser Part Number 454-W25Q80DVSNIG
U4: ICE40LP384-SG32; HVQFN-32-1EP_5x5mm_P0.5mm_EP3.1x3.1mm
Y1: 815-ABM8AIG-12MHZ1ZT; ABM8AIG25000MHZ122ZT3
Y2: ASFL1-100.000MHZ-L-T; ASFL1; Manufacturer_Part_Number ASFL1-100.000MHZ-L-T

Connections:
+1V2: C4.1, C14.1, C15.1, U2.5 (VOUT), U4.25 (VCC)
+2V5: C12.1, C13.1, D1.1 (K), U4.24 (VPP_2V5)
+3V3: C2.1, C3.1, C10.1, C11.1, C16.1, C17.1, C18.1, C19.1, C20.1, C21.1, C22.1, C23.1, C24.1, C25.1, D1.2 (A), J2.1, J3.1, R4.1, R5.1, R6.2, R7.2, R8.2, R9.2, U1.5 (VOUT), U2.1 (VIN), U2.3 (EN), U3.8 (VCC), U4.4 (VCCIO_3), U4.9 (VCCIO_2), U4.16 (VCC_SPI), U4.17 (VCCIO_1), U4.28 (VCCIO_0), Y2.1 (TRI-STATE), Y2.4 (VDD)
+5V: C1.1, C5.1, C6.1, D3.2 (A2), IC1.1 (~RST), IC1.18 (VDD), J1.A4 (VBUS), J1.A9 (VBUS), J1.B4 (VBUS), J1.B9 (VBUS), U1.1 (VIN), U1.3 (STBY)
/CLK_IN: U4.29 (IOT_49_GBIN0), Y2.3 (OUTPUT)
CRESET_B: Q1.3 (C), R9.1, U4.10 (CRESET_B)
CRESET_B_CTL: IC1.3 (GP1), R11.2
GND: C1.2, C2.2, C3.2, C4.2, C5.2, C6.2, C7.2, C8.2, C9.2, C10.2, C11.2, C12.2, C13.2, C14.2, C15.2, C16.2, C17.2, C18.2, C19.2, C20.2, C21.2, C22.2, C23.2, C24.2, C25.2, D2.1 (A1), D3.1 (A1), D4.1 (A1), IC1.17 (VSS), IC1.21 (EP), J1.A1 (GND), J1.A12 (GND), J1.B1 (GND), J1.B12 (GND), J2.10, J3.10, Q1.2 (E), R1.2, R2.2, R10.1, U1.2 (GND), U2.2 (GND), U3.4 (GND), U4.3 (GND), U4.21 (GND), U4.33 (EXP), Y1.2, Y1.4, Y2.2 (GND)
IOL_2A: J3.2, U4.2 (IOL_2A)
IOL_2B: J3.3, U4.1 (IOL_2B)
IOL_4A: J3.7, U4.5 (IOL_4A)
IOL_4B_GBIN7: J2.2, U4.6 (IOL_4B_GBIN7)
IOL_5A_GBIN6: J2.4, U4.8 (IOL_5A_GBIN6)
IOL_5B: J2.3, U4.7 (IOL_5B)
IOR_34: J2.5, U4.18 (IOR_34)
IOR_35_GBIN3: J2.6, U4.19 (IOR_35_GBIN3)
IOR_36_GBIN2: J2.7, U4.20 (IOR_36_GBIN2)
IOR_38: J2.8, U4.22 (IOR_38)
IOR_39: J2.9, U4.23 (IOR_39)
IOT_45: J3.9, U4.26 (IOT_45)
IOT_47: J3.8, U4.27 (IOT_47)
IOT_50_GBIN1: J3.6, U4.30 (IOT_50_GBIN1)
IOT_52: J3.4, U4.32 (IOT_52)
IOT_53: J3.5, U4.31 (IOT_53)
MISO: IC1.10 (MISO), U3.2 (DO_(IO1)), U4.12 (IOB_24_SDO)
MOSI: IC1.6 (MOSI), U3.5 (DI_(IO0)), U4.13 (IOB_25_SDI)
unnamed: D5.2 (A), R8.1, U4.11 (CDONE)
unnamed: D5.1 (K), R10.2
unnamed: C7.1, IC1.19 (OSC1), R3.2, Y1.3
unnamed: C8.1, IC1.20 (OSC2), R3.1, Y1.1
unnamed: C9.1, IC1.14 (VUSB)
unnamed: J1.A5 (CC1), R1.1
unnamed: J1.B5 (CC2), R2.1
unnamed: Q1.1 (B), R11.1
unnamed: R4.2, U3.7 (/HOLD_(IO3))
unnamed: R5.2, U3.3 (/WP_(IO2))
SCK: IC1.8 (SCK), R6.1, U3.6 (CLK), U4.15 (IOB_26_SCK)
SS: IC1.2 (GP0), R7.1, U3.1 (/CS), U4.14 (IOB_27_SS)
USB_D+: D4.2 (A2), IC1.16 (D+), J1.A6 (D+), J1.B6 (D+)
USB_D-: D2.2 (A2), IC1.15 (D-), J1.A7 (D-), J1.B7 (D-)

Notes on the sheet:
USB-SPI Bridge
SPI Flash
Power Supplies
Outputs
max 10us VCC to CS activity
C_{Load} = 18pF C_{Stray} = assume 4pF C_{Load Caps} = (C_{Load} - C_{Stray}) * 2 C_{Load Caps} = 24pF per cap
FPGA
USB Connector
FPGA Decoupling

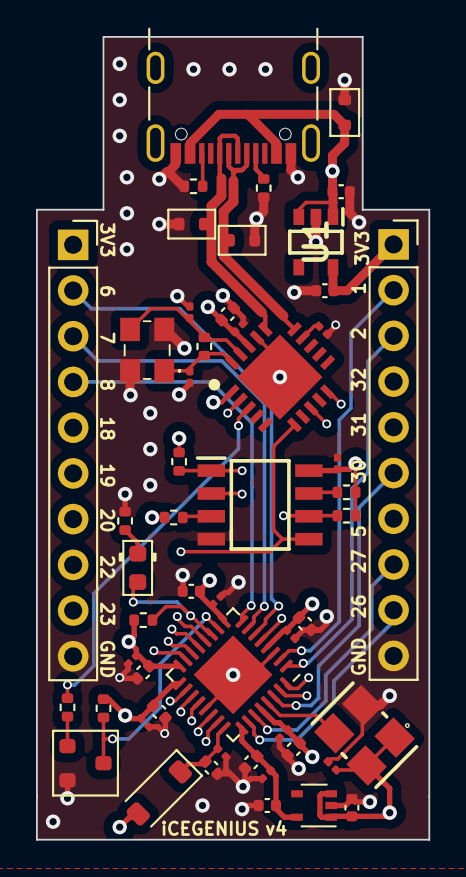
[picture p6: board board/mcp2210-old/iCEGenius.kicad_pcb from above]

Board: 6 copper layers, 21.8 x 44.6 mm, 52 parts (0 on the bottom side), 40 nets.

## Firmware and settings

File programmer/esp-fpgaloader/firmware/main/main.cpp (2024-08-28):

#include <stdint.h>
#include <stdio.h>
#include <string.h>
#include <stdlib.h>
#include <inttypes.h>
#include "freertos/FreeRTOS.h"
#include "freertos/task.h"
#include "freertos/queue.h"
#include "driver/spi_master.h"
#include "driver/gpio.h"
#include "rom/spi_flash.h"
#include "esp_flash_spi_init.h"
#include "esp_log.h"

// pin config
constexpr gpio_num_t SPI_MOSI_PIN = GPIO_NUM_5;
constexpr gpio_num_t SPI_MISO_PIN = GPIO_NUM_3;
constexpr gpio_num_t SPI_SCK_PIN  = GPIO_NUM_4;
constexpr gpio_num_t CS_PIN       = GPIO_NUM_18;
constexpr gpio_num_t CRESET_B_PIN = GPIO_NUM_19;

constexpr uint16_t BASE_ADDR = 0x0000;

static const char *TAG = "iCEGenius";

// state machine enum
typedef enum {
    IDLE,
    RXING,
    ERASE_FLASH,
    WRITE_FLASH,
} State_t;

static State_t curr_state = State_t::IDLE;

extern "C" void app_main() {
    ESP_LOGI(TAG, "Starting iCEGenius programmer");
    // 1. init spi bus, gpios, and usb serial
    // gpio for creset_b
    gpio_config_t creset_b_config = { .pin_bit_mask = (1ULL << CRESET_B_PIN),
                                      .mode         = GPIO_MODE_OUTPUT_OD,
                                      .pull_up_en   = GPIO_PULLUP_DISABLE,
                                      .pull_down_en = GPIO_PULLDOWN_DISABLE,
                                      .intr_type    = GPIO_INTR_DISABLE };

    ESP_ERROR_CHECK(gpio_config(&creset_b_config));
    gpio_set_level(CRESET_B_PIN, 1); // let float, pulled up externally

    // spi for eeprom
    spi_bus_config_t spi_config = { .mosi_io_num     = SPI_MOSI_PIN,
                                    .miso_io_num     = SPI_MISO_PIN,
                                    .sclk_io_num     = SPI_SCK_PIN,
                                    .quadwp_io_num   = -1,
                                    .quadhd_io_num   = -1,
                                    .max_transfer_sz = 256 };

    ESP_ERROR_CHECK(spi_bus_initialize(SPI2_HOST, &spi_config, SPI_DMA_CH_AUTO));

    // setup flash
    static esp_flash_t *flash;
    static esp_flash_spi_device_config_t flash_spi_config = { .host_id        = SPI2_HOST,
                                                              .cs_io_num      = CS_PIN,
                                                              .io_mode        = SPI_FLASH_SLOWRD,
                                                              .input_delay_ns = 0,
                                                              .freq_mhz       = 5 };
    ESP_ERROR_CHECK(spi_bus_add_flash_device(&flash, &flash_spi_config));
    ESP_ERROR_CHECK(esp_flash_init(flash));
    while (true) {
        switch (curr_state) {
            case State_t::IDLE: {
                // 2. wait for rx from serial while plugged in
                break;
            }

            case State_t::RXING: {
                break;
            }

            case State_t::ERASE_FLASH: {
                break;
            }

            case State_t::WRITE_FLASH: {
                curr_state = State_t::IDLE;
                break;
            }

            default: break;
        }
    }


    // 3. rxing, save data to memory or stream (not decided yet), connect to flash
    // 4. after done or while streaming, pull creset_b low to force fpga into reset
    // 5. write data to flash over spi
    // 6. after write, disconnect from flash and release creset_b
    // 7. sleep(if possbile) or wait until next rx from serial
}

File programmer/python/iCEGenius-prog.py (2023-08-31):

import time
import sys
from mcp2210 import MCP2210

def configure_first_time(device: MCP2210) -> None:
    # set iCEGenius name
    device.product_name = "iCEGenius"
    device.manufacturer_name = "Dirk Thieme"

    # configure default startup settings
    startup_chip_settings = device.boot_chip_settings
    startup_spi_settings = device.boot_transfer_settings

    # set gpio 0 to cs
    startup_chip_settings.pin_designations[0] = 0x01

    # set the rest to GPIOs
    for i in range(1, 10):
        startup_chip_settings.pin_designations[i] = 0x00

    # turn all GPIOs to outputs and off
    startup_chip_settings.gpio_directions = 0x00
    startup_chip_settings.gpio_outputs = 0x00
    
    # configure spi timing
    startup_spi_settings.bit_rate = 0x000F_4240 # 1MHz
    startup_spi_settings.idle_cs = 0x00
    startup_spi_settings.active_cs = 0x00
    
    # set defaults
    device.boot_chip_settings = startup_chip_settings
    device.boot_transfer_settings = startup_spi_settings

def main(bitstream):
    # default vendor and product IDs for mcp2210s
    DEFAULT_VID = 0x4D8
    DEFAULT_PID = 0xDE

    # try and open device
    try:
        device = MCP2210(DEFAULT_VID, DEFAULT_PID)
    except OSError as e:
        print("No iCEGenius found...")
        print(f"OSError: {e}")
        return

    # if device opened but unused, set defaults
    if device.product_name != "iCEGenius" and device.manufacturer_name != "Dirk Thieme":
        configure_first_time(device)

    # set pin 1 high to pull CRESET_B low
    curr_settings = device.chip_settings
    curr_settings.gpio_outputs = 0x02
    device.chip_settings = curr_settings
    
    # activate cs line
    curr_settings = device.transfer_settings
    curr_settings.active_cs = 0x01
    device.transfer_settings = curr_settings
    
    # transmit data
    device.transfer(bitstream)
    
    # deactivate cs line
    curr_settings = device.transfer_settings
    curr_settings.active_cs = 0x00
    device.transfer_settings = curr_settings

    time.sleep(1)

    # turn off pin 1
    curr_settings = device.chip_settings
    curr_settings.gpio_outputs = 0x00
    device.chip_settings = curr_settings


if __name__ == '__main__':
    if len(sys.argv) != 2:
        print("Usage: iCEGenius-prog /path/to/file.bin")
        exit(-1)

    with open(sys.argv[1], 'rb') as file:
        bitstream = file.read()
        
        if len(bitstream) > 0xFFFF:
            print("Bitstream too large to process! MCP2210 only supports a maximum transfer of 65,535 bytes!")
            exit(-1)
        elif len(bitstream) < 0xFFFF:
            bitstream += bytes(0x0) * (0xFFFF - len(bitstream))
        
        main(bitstream)

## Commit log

2023-06-02 updated board to v2, setup vscode extension
2023-06-02 recommited new board files
    [BOM-iCEGenius.csv, bom.xlsx, iCE40PinoutLP384.xlsx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]
2023-06-07 Added software-flowcharts
2023-06-07 Update software-flowcharts
2023-06-10 vscode extension progress
    [CPL-iCEGenius.csv, iCEGenius-CuBottom.gbr, iCEGenius-CuIn1.gbr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]
2023-07-10 linux push
    [BOM-iCEGenius.csv, bom.xlsx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]
2023-08-31 uploaded current state - unfinished
    [bom.xlsx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]
2024-08-26 finished v5 of PCB in ESP32 folder
    [BOM-iCEGenius.csv, bom.xlsx, iCE40PinoutLP384.xlsx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]
2024-08-28 updated extension to automatically install required programs on Windows, macos, and Linux
    [BOM-iCEGenius.csv, bom.xlsx, iCEGenius.kicad_pcb]
